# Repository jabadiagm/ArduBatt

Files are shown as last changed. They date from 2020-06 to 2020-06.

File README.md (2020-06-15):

# ArduBatt
Cargador de baterías con arduino y pantalla táctil

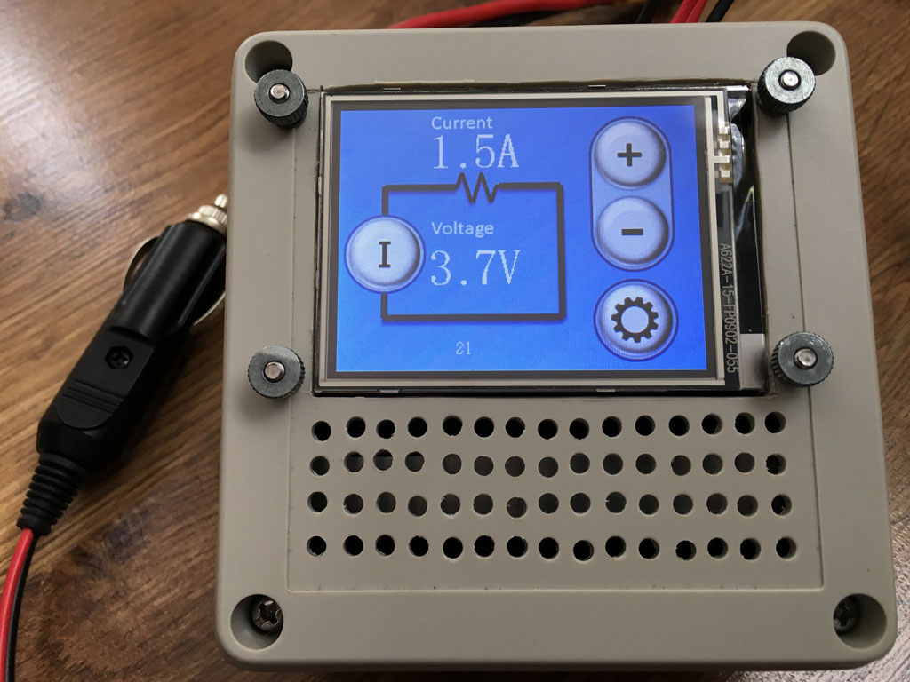
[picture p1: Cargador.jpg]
Cargador


Cargador de baterías basado en un convertidor push-pull de 30W, controlado por un atmega328p, el mismo que utiliza el arduino Uno. Esto permite usar las herramientas y librerías de arduino. El ajuste del cargador se hace desde una pantalla táctil Nextion, que se comunica con el atmega a través del puerto serie.

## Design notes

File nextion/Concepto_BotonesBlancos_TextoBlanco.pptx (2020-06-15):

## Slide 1

Current

0.2 A

+

+

+

V

Voltage

12.5 V

V

PAUSED

62% tamaño real

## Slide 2

Current

0.2 A

+

+

+

V

Voltage

12.5 V

V

PAUSED

62% tamaño real

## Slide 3

Current

0.2 A

+

+

+

V

Voltage

12.5 V

V

PAUSED

62% tamaño real

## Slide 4

Current

0.2 A

+

+

+

V

Voltage

12.5 V

PAUSED

V

62% tamaño real

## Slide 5

Settings

POWER MODE

Voltage
Current
Manual

<

a

V

a

I

a

M

62% tamaño real

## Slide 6

Sensors

<

Set=
PWM=

+

Vi=
Ii=
Vo=
Io=
T=

PAUSED

62% tamaño real

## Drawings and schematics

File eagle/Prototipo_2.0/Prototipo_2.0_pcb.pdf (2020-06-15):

1 2 3

TR1

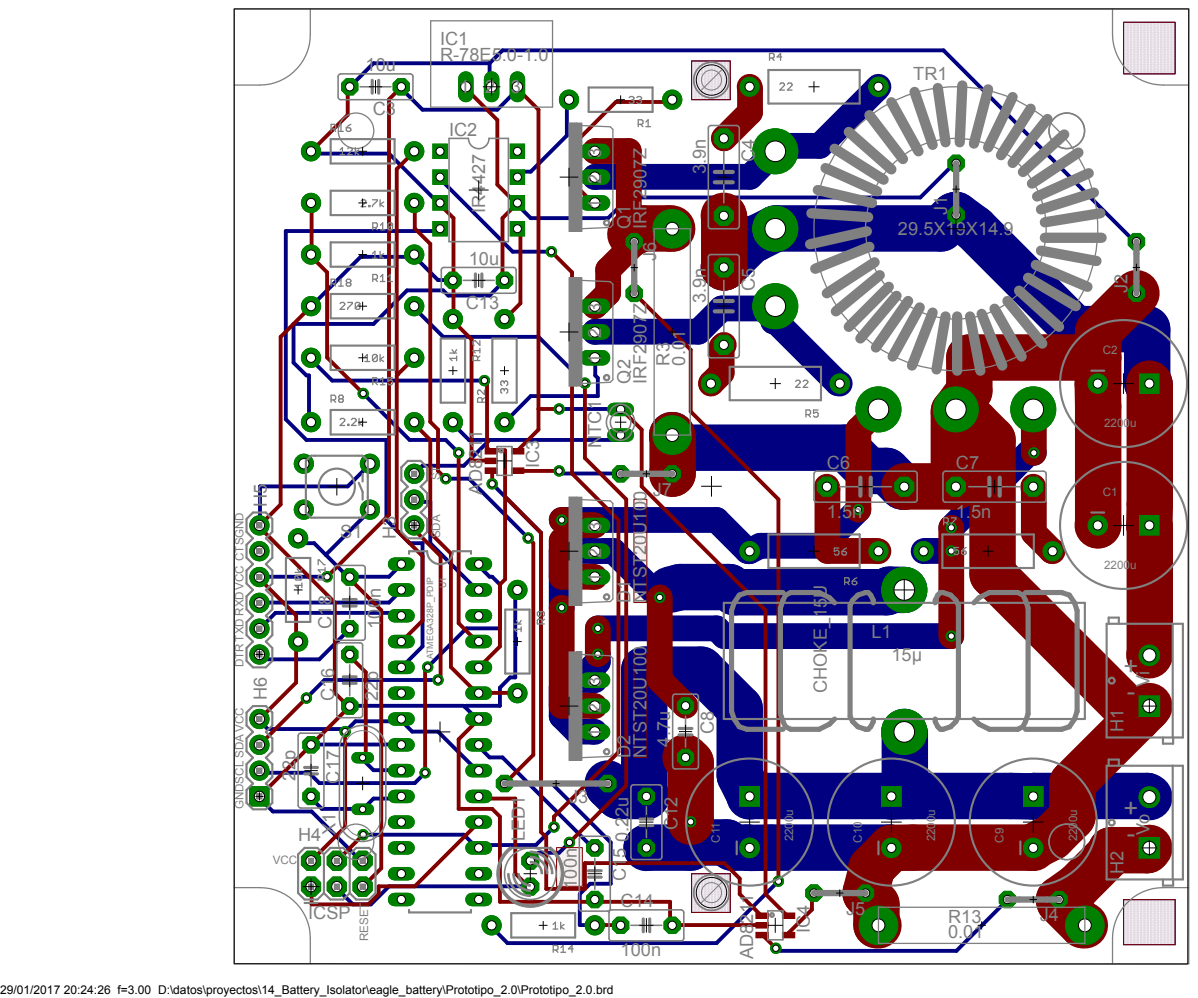
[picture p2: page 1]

DTR TXD RXDVCC CTSGND GNDSCL SDA VCC

L1
15µ

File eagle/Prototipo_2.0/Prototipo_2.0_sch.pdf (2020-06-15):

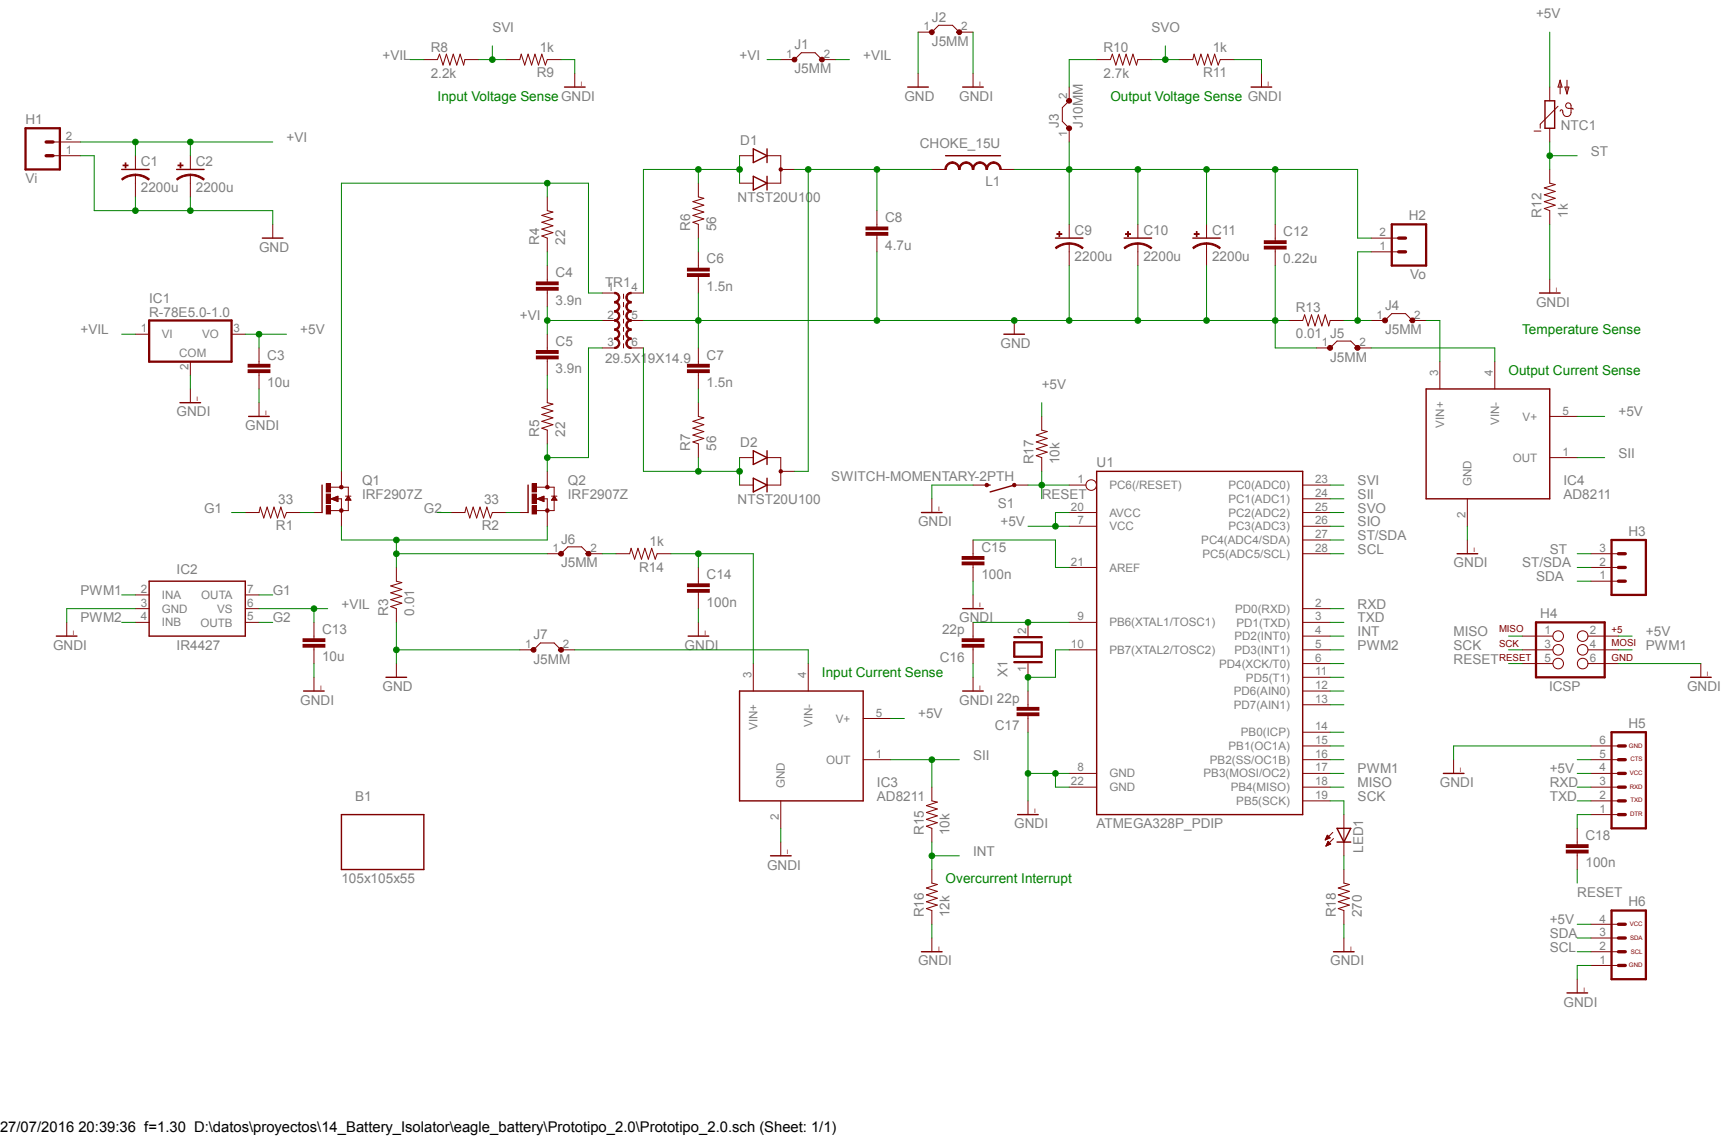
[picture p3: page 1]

27/07/2016 20:39:36 f=1.30 D:\datos\proyectos\14_Battery_Isolator\eagle_battery\Prototipo_2.0\Prototipo_2.0.sch (Sheet: 1/1) ⁵⁶

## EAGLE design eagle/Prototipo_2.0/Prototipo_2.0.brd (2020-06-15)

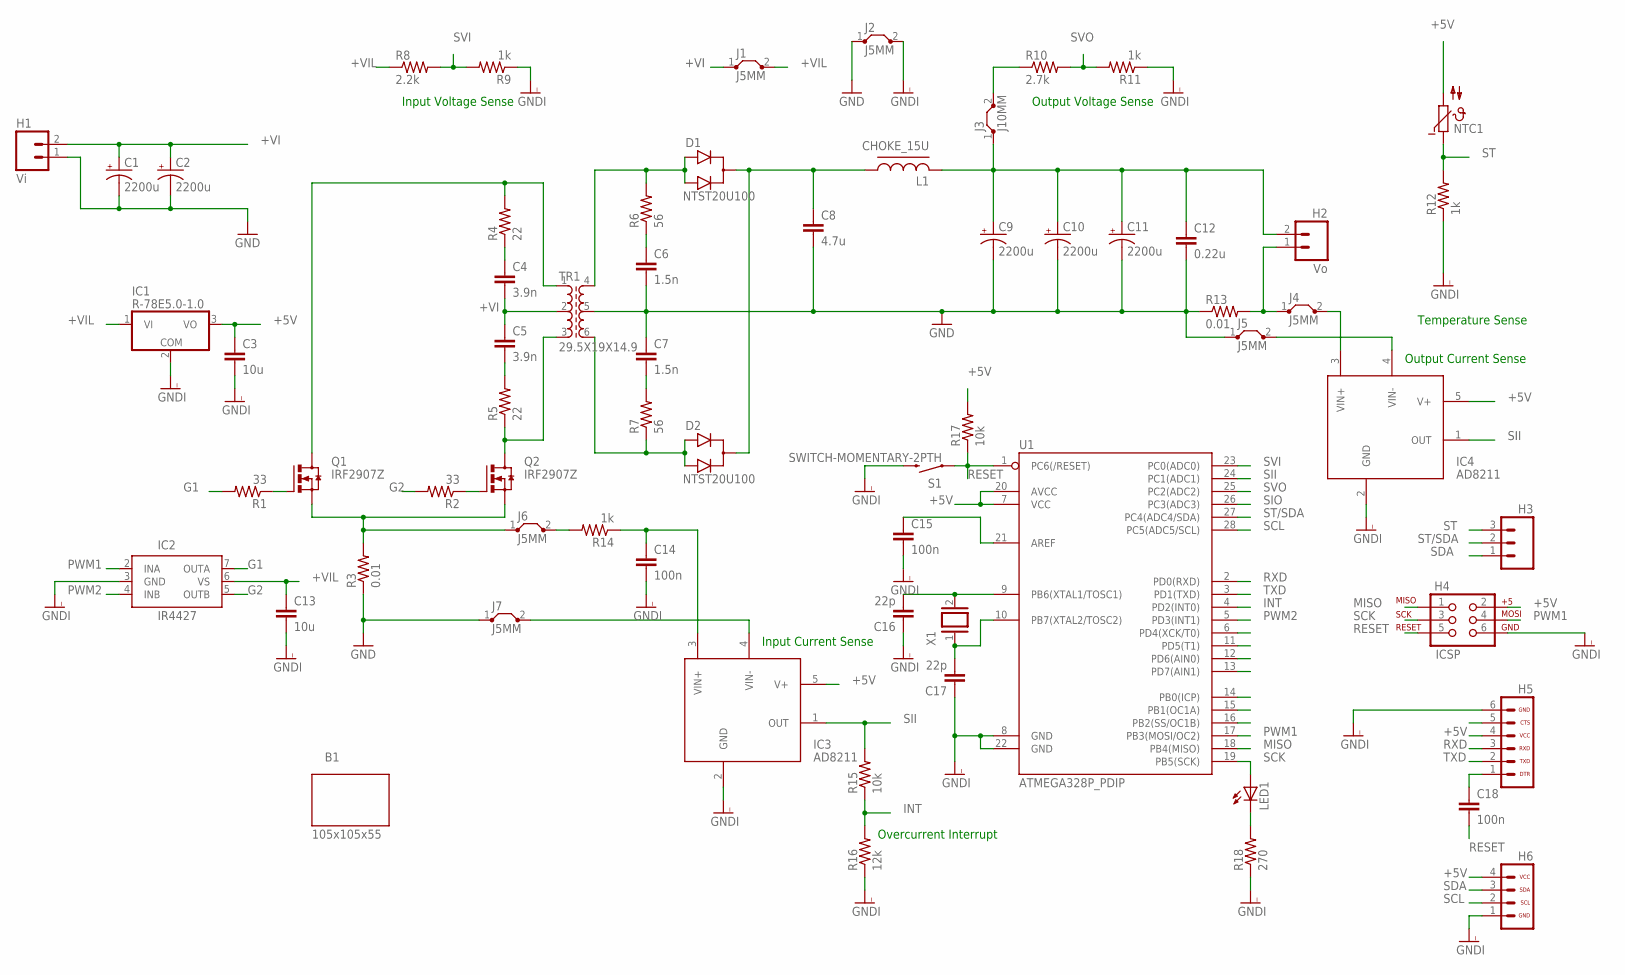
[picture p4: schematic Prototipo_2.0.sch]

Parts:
B1: 105x105x55; BOX_105X105X55
C1, C2, C9, C10, C11: 2200u; CPOL_RADIAL_12.5MM_5MM; MOUSER 667-EEU-FR1V222L
C3, C13: 10u; C5B2.5; MOUSER 810-FK26X7R1C106K
C4, C5: 3.9n; C7.5B3; MOUSER 594-K392K15X7RF53L2
C6, C7: 1.5n; C7.5B3; MOUSER 581-SR151C152KAR
C8: 4.7u; C5B2.5; MOUSER 81-RDEC71H475K2M1H3A
C12: 0.22u; C5B3; MOUSER 80-R82DC3220AA60K
C14, C15, C18: 100n; C5B3; MOUSER 80-R82DC3100AA50J
C16, C17: 22p; C5B2.5; MOUSER 140-50N5-220J-RC
D1, D2: NTST20U100; TO220V
H1: Vi; SCREWTERMINAL-5MM-2
H2: Vo; SCREWTERMINAL-5MM-2
H3: M03PTH; 1X03
H4: ICSP; 2X3
H5: HEADER_SERIAL
H6: HEADER_I2C
IC1: R-78E5.0-1.0
IC2: IR4427; DIL08
IC3, IC4: AD8211; RJ-5
J1, J2, J4, J5, J6, J7: J5MM; 05
J3: J10MM; 10
L1: CHOKE_15U; MOUSER 652-2200LL-150-H-RC
LED1: LED5MM
NTC1: NTC640; P640; MOUSER 594-NTCLE203E3502JB0
Q1, Q2: IRF2907Z; TO220V
R1, R2: 33; AXIAL-0.4; MOUSER 660-MF14DCT52R33R0F
R3, R13: 0.01; RSENSE; MOUSER 5W_66-OAR5R010JLF
R4, R5: 22; AXIAL-0.5; MOUSER 603-MFR50SFTE52-22R
R6, R7: 56; AXIAL-0.5; MOUSER 603-MFR50SFTE52-56R
R8: 2.2k; AXIAL-0.4; MOUSER 660-MF1/4DC1001F
R9, R11, R12, R14: 1k; AXIAL-0.4; MOUSER 660-MF1/4DC1001F
R10: 2.7k; AXIAL-0.4
R15, R17: 10k; AXIAL-0.4; MOUSER 660-MF1/4DC1002F
R16: 12k; AXIAL-0.4; MOUSER 660-MF1/4DCT52R1202F
R18: 270; AXIAL-0.4; MOUSER 660-MF1/4DC2700F
S1: SWITCH-MOMENTARY-2PTH; TACTILE-PTH
TR1: 29.5X19X14.9; CORE_29.5X19X14.9
U1: ATMEGA328P_PDIP; DIL28-3; MOUSER 556-ATMEGA328P-PU
X1: XTAL/S; QS

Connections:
$N1: C8.1, D1.2 (C), D2.2 (C), L1.1
+5V: C3.1, H4.2, H5.4 (4_VCC), H6.4 (4_VCC), IC1.3 (VO), IC3.5 (V+), IC4.5 (V+), NTC1.2, R17.P$2 (2), U1.7 (VCC), U1.20 (AVCC)
+VI: C1.+, C2.+, C4.2, C5.1, H1.2, J1.1, TR1.2
+VIL: C13.1, IC1.1 (VI), IC2.6 (VS), J1.2, R8.P$1 (1)
G1: IC2.7 (OUTA), R1.P$2 (2)
G2: IC2.5 (OUTB), R2.P$2 (2)
GND: C1.-, C2.-, C6.2, C7.1, C8.2, C9.-, C10.-, C11.-, C12.2, H1.1, J2.1, J5.1, J7.1, R3.P$1 (1), R13.P$1 (1), TR1.5
GNDI: C3.2, C13.2, C14.2, C15.2, C16.1, C17.1, H4.6, H5.6 (6_GND), H6.1 (1_GND), IC1.2 (COM), IC2.3 (GND), IC3.2 (GND), IC4.2 (GND), J2.2, R9.P$1 (1), R11.P$1 (1), R12.P$1 (1), R16.P$1 (1), R18.P$1 (1), S1.3 (2), U1.8 (GND), U1.22 (GND)
INT: R15.P$1 (1), R16.P$2 (2), U1.4 (PD2(INT0))
MISO: H4.1, U1.18 (PB4(MISO))
unnamed: Q1.1 (G), R1.P$1 (1)
unnamed: Q2.1 (G), R2.P$1 (1)
unnamed: C18.1, H5.1 (1_DTR)
unnamed: C7.2, R7.P$2 (2)
unnamed: C5.2, R5.P$2 (2)
unnamed: J3.2, R10.P$1 (1)
unnamed: C6.1, R6.P$1 (1)
unnamed: D1.1 (A1), D1.3 (A2), R6.P$2 (2), TR1.4
unnamed: D2.1 (A1), D2.3 (A2), R7.P$1 (1), TR1.6
unnamed: C9.+, C10.+, C11.+, C12.1, H2.2, J3.1, L1.2
unnamed: C4.1, R4.P$1 (1)
unnamed: Q1.2 (D), R4.P$2 (2), TR1.1
unnamed: Q2.2 (D), R5.P$1 (1), TR1.3
unnamed: J6.1, Q1.3 (S), Q2.3 (S), R3.P$2 (2)
unnamed: H2.1, J4.1, R13.P$2 (2)
unnamed: IC4.3 (VIN+), J4.2
unnamed: IC4.4 (VIN-), J5.2
unnamed: C14.1, IC3.3 (VIN+), R14.P$1 (1)
unnamed: IC3.4 (VIN-), J7.2
unnamed: J6.2, R14.P$2 (2)
unnamed: C16.2, U1.9 (PB6(XTAL1/TOSC1)), X1.2
unnamed: C17.2, U1.10 (PB7(XTAL2/TOSC2)), X1.1
unnamed: LED1.K (C), R18.P$2 (2)
unnamed: C15.1, U1.21 (AREF)
PWM1: H4.4, IC2.2 (INA), U1.17 (PB3(MOSI/OC2))
PWM2: IC2.4 (INB), U1.5 (PD3(INT1))
RESET: C18.2, H4.5, R17.P$1 (1), S1.1, U1.1 (PC6(/RESET))
RXD: H5.3 (3_RXD), U1.2 (PD0(RXD))
SCK: H4.3, LED1.A, U1.19 (PB5(SCK))
SCL: H6.2 (2_SCL), U1.28 (PC5(ADC5/SCL))
SDA: H3.1, H6.3 (3_SDA)
SII: IC3.1 (OUT), IC4.1 (OUT), R15.P$2 (2), U1.24 (PC1(ADC1))
SIO: U1.26 (PC3(ADC3))
ST: H3.3, NTC1.1, R12.P$2 (2)
ST/SDA: H3.2, U1.27 (PC4(ADC4/SDA))
SVI: R8.P$2 (2), R9.P$2 (2), U1.23 (PC0(ADC0))
SVO: R10.P$2 (2), R11.P$2 (2), U1.25 (PC2(ADC2))
TXD: H5.2 (2_TXD), U1.3 (PD1(TXD))

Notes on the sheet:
Temperature Sense
Input Voltage Sense
Output Voltage Sense
Output Current Sense
Input Current Sense
Overcurrent Interrupt

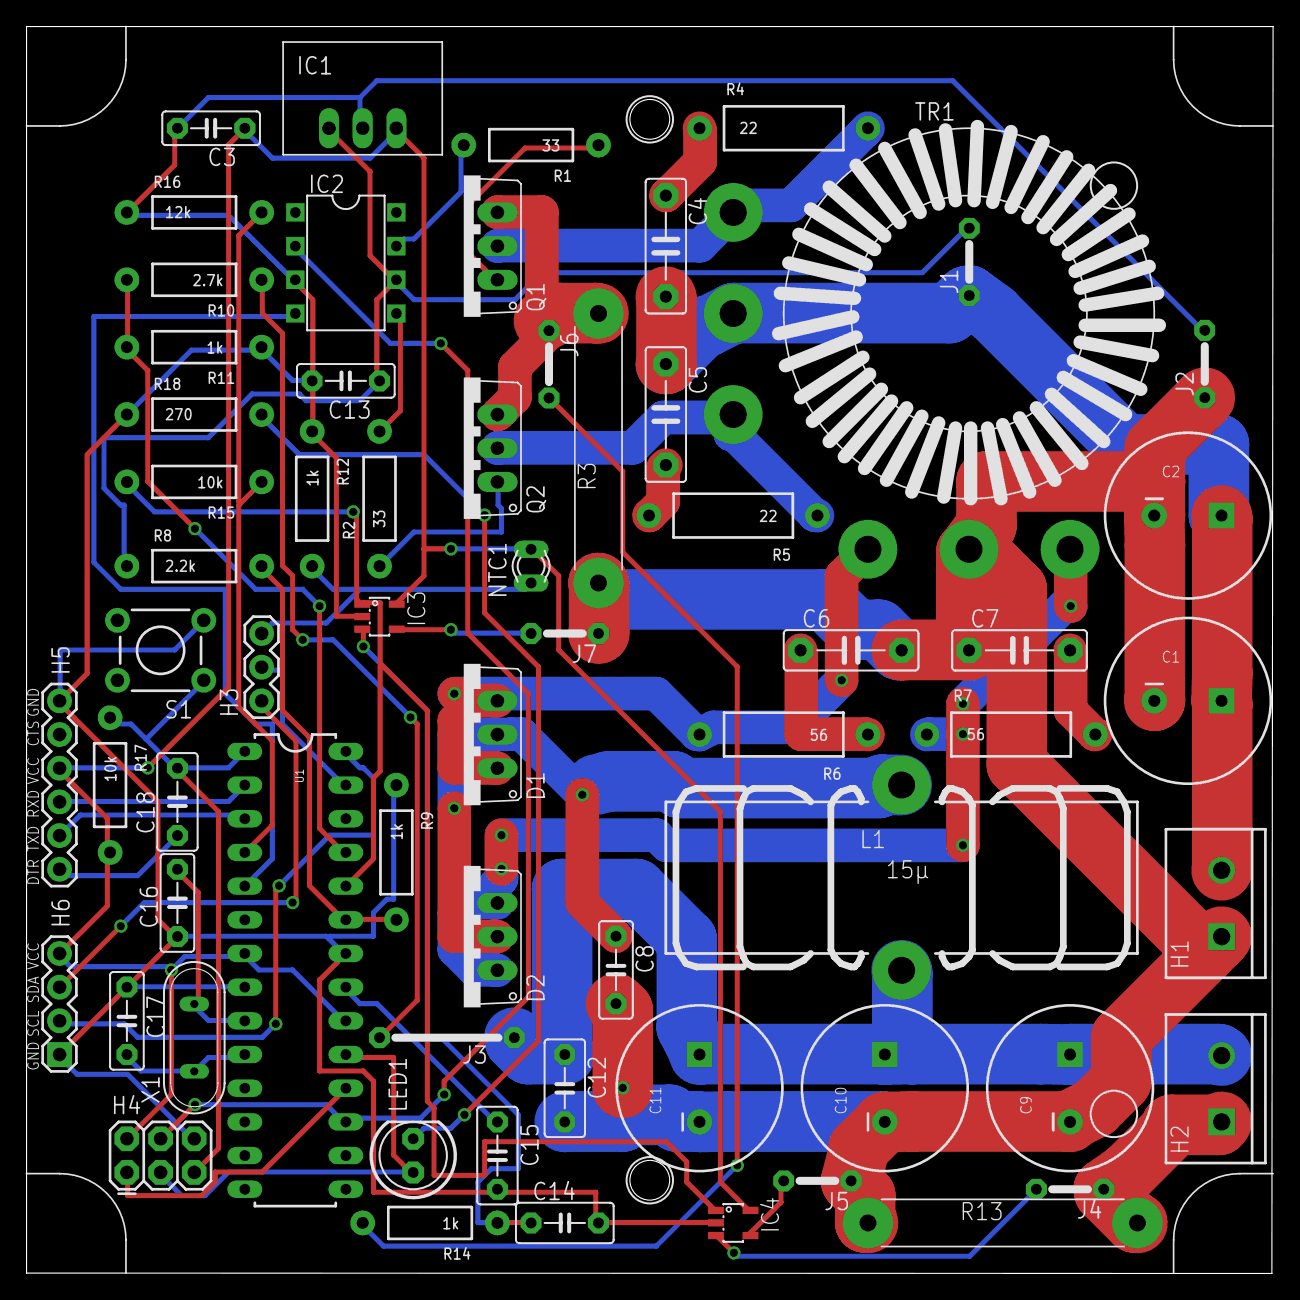
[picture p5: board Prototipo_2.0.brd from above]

Board: 2 copper layers, 94.0 x 94.0 mm, 65 parts (0 on the bottom side), 47 nets.

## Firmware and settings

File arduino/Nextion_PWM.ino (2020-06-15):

#include "D:\datos\Arduino\libraries\Timer2PWM\src\Timer2PWM.h"
#include "D:\datos\Arduino\libraries\Sensor\src\Sensor.h"
#include "D:\datos\Arduino\libraries\Nextion\src\Nextion.h"
#include "D:\datos\Arduino\libraries\Functions\src\Functions.h"
#include "D:\datos\Arduino\libraries\MemoryFree\MemoryFree.h"
#include "D:\datos\Arduino\libraries\PID\src\PID.h"

class Padre
{
public:
	Padre()
	{
		Serial.println("constructor Padre");
	}
	virtual void Comun()
	{
		Serial.println("Comun Padre");
	}
	virtual void Prueba()
	{
		Comun();
	}
};

class Hijo :public Padre
{
public:
	Hijo()
	{
		Serial.println(F("constructor Hijo"));
		//Padre();
	}
	void Comun()
	{
		Serial.println("Comun Hijo");
		Padre::Comun();
	}
};

class CtNextionPWM;


void blink() {
	pinMode(13, OUTPUT);
	long counter;
	for (counter = 0; counter < 3; counter++) {
		digitalWrite(13, HIGH);   // turn the LED on (HIGH is the voltage level)
		delay(1000);              // wait for a second
		digitalWrite(13, LOW);    // turn the LED off by making the voltage LOW
		delay(1000);              // wait for a second
	}

}


bool echo = false;
//float setpoint = 0; //voltage/current reference

void bip() { Serial.println("Bip"); }

// defines for setting and clearing register bits
#ifndef cbi
#define cbi(sfr, bit) (_SFR_BYTE(sfr) &= ~_BV(bit))
#endif
#ifndef sbi
#define sbi(sfr, bit) (_SFR_BYTE(sfr) |= _BV(bit))
#endif

void fastADC12_5()
//adjust prescaler to get faster conversion (12.5KHz)
{
	// set prescale to 64
	sbi(ADCSRA, ADPS2);
	sbi(ADCSRA, ADPS1);
	cbi(ADCSRA, ADPS0);
}

//page objects constants
//Events
const byte EV_POWERSHORTPRESS = 1;
const byte EV_POWERLONGPRESS = 2;
const byte EV_PLUSSHORTPRESS = 3;
const byte EV_PLUSLONGPRESS = 4;
const byte EV_MINUSSHORTPRESS = 5;
const byte EV_MINUSLONGPRESS = 6;
const byte EV_SETTINGSSHORTPRESS = 7;
const byte EV_SETTINGSLONGPRESS = 8;
const byte EV_BACKSHORTPRESS = 9;
const byte EV_BACKLONGPRESS = 10;
const byte EV_VOLTAGECHECKBOX = 11;
const byte EV_CURRENTCHECKBOX = 12;
const byte EV_MANUALCHECKBOX = 13;
//Variables
const byte VAR_SENSORVI = 128;
const byte VAR_SENSORII = 129;
const byte VAR_SENSORVO = 130;
const byte VAR_SENSORIO = 131;
const byte VAR_SENSORT = 132;
const byte VAR_FSETPOINT = 133;
const byte VAR_ISETPOINT = 134;
const byte VAR_POWERMODE = 135;
const byte VAR_LOOPSTATUS = 136;



typedef enum enumLoopStatus {
	lsStop = 0,
	lsPause = 1,
	lsRun = 2,
	lsMalfunction = 3,
	lsNoState=99
} ;

typedef enum powerMode {
	pmVoltage=0,
	pmCurrent=1,
	pmManual=2
};


class iCtNextionPWM {
public:
	virtual void Init() {}
	virtual void ShowMain() {}
	virtual void ShowMainVoltage() {}
	virtual void ShowMainCurrent() {}
	virtual void ShowMainManual() {}
	virtual void ShowSettings() {}
	virtual void ShowSensors() {}
	virtual void ShowSensorsVoltage() {}
	virtual void ShowSensorsCurrent() {}
	virtual void ShowSensorsManual() {}
	virtual void ShowAlarm(char *alarmText) {}
	virtual void ProcessEvent(byte eventId) {} //button click
	virtual void DisplayVariables() {} //show variables during loop
	virtual void DisplayVariable(byte variableId) {} //show single variable
};

class config {
public:
	config();
	powerMode pwMode;
	float fSetpoint; //voltage/current reference
	int iSetpoint; //manual mode reference
	bool nextionOK; //true when screen is ready
	const float INCREMENTVOLTAGE=0.5; // +/- 0.5V
	const float INCREMENTCURRENT = 0.1; // +/- 0.1A
	const int INCREMENTMANUAL = 1; // +/-1 in pwm
	const float MAXVOLTAGE = 20; //maximum output voltage
	const float MAXCURRENT = 4; //maximum current
	const int MAXMANUAL = 127; //maximum pwm value
	const int MINMANUAL = 0; //minimum pwm value due to switching dead times
	const unsigned long TIMEADQUIREDATA = 500; //time (us) to read analog sensors
	const unsigned long TIMECONTROL = 5000; // 5000; //time (us) to control
	const unsigned long TIMEREFRESHDATA = 1000; //time (ms) to update screen data
	const int TIMESHORTPRESS = 450; //max time to keep pressing a button to take as short press
private:
}config;

config::config(){
	pwMode = pmVoltage;
	nextionOK = false;
	iSetpoint = MINMANUAL;
	fSetpoint = 0;
}


struct NextionListener : public NextionEvent
{
	using NextionEvent::Event;

	void Event(char *eventText)
	{
		static unsigned long timeButtonPress; //when a button was last pressed
#if defined(__AVR_ATmega1280__) || defined(__AVR_ATmega2560__)
		Serial.print("Event:");
		Serial.println(eventText);
#endif
		//main screen
		//+ button
		if (strcmp_P(eventText, PSTR("65000201")) == 0) { //+ button pressed
			timeButtonPress = millis();
		}
		if (strcmp_P(eventText,PSTR( "65000200")) == 0) { //+ button released
			if ((millis() - timeButtonPress) < config.TIMESHORTPRESS) {
				//buttonPlusShortPress();
				Controller->ProcessEvent(EV_PLUSSHORTPRESS);
			}
			else {
				//buttonPlusLongPress();
				Controller->ProcessEvent(EV_PLUSLONGPRESS);
			}
		}
		//- button
		if (strcmp_P(eventText, PSTR("65000301")) == 0) { //- button pressed
			timeButtonPress = millis();
		}
		if (strcmp_P(eventText, PSTR("65000300")) == 0) { //- button released
			if ((millis() - timeButtonPress) < config.TIMESHORTPRESS) {
				//buttonMinusShortPress();
				Controller->ProcessEvent(EV_MINUSSHORTPRESS);
			}
			else {
				//buttonMinusLongPress();
				Controller->ProcessEvent(EV_MINUSLONGPRESS);
			}
		}
		//power button
		if (strcmp_P(eventText, PSTR("65000501")) == 0) { //power button pressed
			timeButtonPress = millis();
		}
		if (strcmp_P(eventText, PSTR("65000500")) == 0) { //power button released
			if ((millis() - timeButtonPress) < config.TIMESHORTPRESS) {
				//buttonPowerShortPress();
				Controller->ProcessEvent(EV_POWERSHORTPRESS);
			}
			else {
				//buttonPowerLongPress();
				Controller->ProcessEvent(EV_POWERLONGPRESS);
			}
		}
		//settings button
		if (strcmp_P(eventText, PSTR("65000401")) == 0) { //settings button pressed
			timeButtonPress = millis();
		}
		if (strcmp_P(eventText, PSTR("65000400")) == 0) { //settings button released
			if ((millis() - timeButtonPress) < config.TIMESHORTPRESS) {
				//buttonSettingsShortPress();
				Controller->ProcessEvent(EV_SETTINGSSHORTPRESS);
			}
			else {
				//buttonSettingsLongPress();
				Controller->ProcessEvent(EV_SETTINGSLONGPRESS);
			}
		}
		//settings screen
		//back button
		if (strcmp_P(eventText, PSTR("65010101")) == 0) { //back button pressed
			timeButtonPress = millis();
		}
		if (strcmp_P(eventText, PSTR("65010100")) == 0) { //back button released
			if ((millis() - timeButtonPress) < config.TIMESHORTPRESS) {
				//buttonBackShortPress();
				Controller->ProcessEvent(EV_BACKSHORTPRESS);
			}
			else {
				//buttonBackLongPress();
				Controller->ProcessEvent(EV_BACKLONGPRESS);
			}
		}
		//voltage checkbox
		if (strcmp_P(eventText, PSTR("65010201")) == 0) { 
			//checkVoltagePress();
			Controller->ProcessEvent(EV_VOLTAGECHECKBOX);
		}

		//current checkbox
		if (strcmp_P(eventText,PSTR("65010301")) == 0) {
			//checkCurrentPress();
			Controller->ProcessEvent(EV_CURRENTCHECKBOX);
		}

		//manual checkbox
		if (strcmp_P(eventText, PSTR("65010401")) == 0) {
			//checkManualPress();
			Controller->ProcessEvent(EV_MANUALCHECKBOX);
		}
		//sensors screen
		//back button
		if (strcmp_P(eventText, PSTR("65020D01")) == 0) { //back button pressed
			timeButtonPress = millis();
		}
		if (strcmp_P(eventText, PSTR("65020D00")) == 0) { //back button released
			if ((millis() - timeButtonPress) < config.TIMESHORTPRESS) {
				//buttonBackShortPress();
				Controller->ProcessEvent(EV_BACKSHORTPRESS);
			}
			else {
				//buttonBackLongPress();
				Controller->ProcessEvent(EV_BACKLONGPRESS);
			}
		}
		//power button
		if (strcmp_P(eventText, PSTR("65020301")) == 0) { //power button pressed
			timeButtonPress = millis();
		}
		if (strcmp_P(eventText, PSTR("65020300")) == 0) { //power button released
			if ((millis() - timeButtonPress) < config.TIMESHORTPRESS) {
				//buttonPowerShortPress();
				Controller->ProcessEvent(EV_POWERSHORTPRESS);
			}
		}
		//+ button
		if (strcmp_P(eventText, PSTR("65020401")) == 0) { //+ button pressed
			timeButtonPress = millis();
		}
		if (strcmp_P(eventText, PSTR("65020400")) == 0) { //+ button released
			if ((millis() - timeButtonPress) < config.TIMESHORTPRESS) {
				//buttonPlusShortPress();
				Controller->ProcessEvent(EV_PLUSSHORTPRESS);
			}
			else {
				//buttonPlusLongPress();
				Controller->ProcessEvent(EV_PLUSLONGPRESS);
			}
		}
		//- button
		if (strcmp_P(eventText, PSTR("65020501")) == 0) { //- button pressed
			timeButtonPress = millis();
		}
		if (strcmp_P(eventText, PSTR("65020500")) == 0) { //- button released
			if ((millis() - timeButtonPress) < config.TIMESHORTPRESS) {
				//buttonMinusShortPress();
				Controller->ProcessEvent(EV_MINUSSHORTPRESS);
			}
			else {
				//buttonMinusLongPress();
				Controller->ProcessEvent(EV_MINUSLONGPRESS);
			}
		}
	}
	iCtNextionPWM *Controller;
} NextionListener;



/*void echo_string_serial(char *line, int n_bytes) {
	int counter;
	char output[200];
	hex_string2string(line, n_bytes, output);
	output[2 * n_bytes] = 0;
	echo_println(output);
} */
void echo_print(String line) {
	if (echo) Serial.print(line);
}
void echo_println(String line) {
	if (echo) Serial.println(line);
}

#if defined(__AVR_ATmega1280__) || defined(__AVR_ATmega2560__)
	Nextion screen(&Serial3, &NextionListener);
#else
	Nextion screen(&Serial, &NextionListener);
#endif
enumLoopStatus loopStatus = lsStop;


struct AlarmListener : public AlarmEvent
{
	using AlarmEvent::Alarm;

	void Alarm(String AlarmText)
	{
		//if the screen is working, show error in status line. if not, send by serial
		byte ret;
		char command[30]="";
		//String command;
		loopStatus = lsMalfunction; 
		Timer2PWM.end(); //stop power
		if (config.nextionOK == true) {
			AlarmText.toCharArray(command, AlarmText.length()+1,0);
			Controller->ShowAlarm(command);
			/*
			//if (config.pageNumber != 0) buttonBackShortPress(); //alarms are shown in main screen
			ret = screen.sendCommand("t2.pco=63488"); //status line to red
			if (!ret) {
				command = "t2.txt=\"" + AlarmText + "\"";
			}
			if (!ret) ret = screen.sendCommand(command);
			if (!ret) ret = screen.sendCommand("ref t2");
			
			//change power icon to red
			switch (config.pwMode) {
			case pmVoltage:
				if (!ret) ret = screen.sendCommand("b3.picc=3");
				break;
			case pmCurrent:
				if (!ret) ret = screen.sendCommand("b3.picc=7");
				break;
			case pmManual:
				if (!ret) ret = screen.sendCommand("b3.picc=11");
				break;
			}
			if (!ret) ret = screen.sendCommand("t0.txt=\"0A\""); //current to 0
			if (!ret) ret = screen.sendCommand("t1.txt=\"0V\""); //voltage to 0
			if (!ret) ret = screen.sendCommand("ref b3"); */
		}
		if (config.nextionOK == false || ret!=0) {
			byte counter;
			while (1) {
				Serial.println(AlarmText);
				for (counter = 0; counter < 50; counter++) {
					digitalWrite(13, HIGH);
					delay(25);
					digitalWrite(13, LOW);
					delay(25);
				}
			}
		}
	}
	iCtNextionPWM *Controller;
} AlarmListener;

SENSOR SensorVi(0, 0.0156, "Vi", 22, &AlarmListener,40, (float)config.TIMEADQUIREDATA / 1000000); //input voltage
SENSOR SensorIi(1, 0.0244, "Ii", 200, &AlarmListener,1, (float)config.TIMEADQUIREDATA / 1000000); //input current
SENSOR SensorVo(2, 0.018, "Vo", 20, &AlarmListener,50, (float)config.TIMEADQUIREDATA / 1000000); //output voltage
SENSOR SensorIo(3, 0.0244, "Io", 15, &AlarmListener,200,(float)config.TIMEADQUIREDATA/1000000); //output current
NTC5K25 SensorT(4, "T", 70, &AlarmListener); //Temperature
fPID ControllerI(2, 10, 0, (float)config.TIMECONTROL/1000000);
fPID ControllerV(0.01, 0.2, 0, (float)config.TIMECONTROL/1000000);

unsigned long counterAdquire=0; //number of times adquire() is called
unsigned long counterControl = 0; //number of times control() is called
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
void loop()
{
	String command;
	String response;
	

	/*long counter;
	Serial.begin(38400);
	config.pwMode = pmVoltage;
	config.fSetpoint = 5;
	run();
	for (counter = 0; counter < 500000; counter++) {

		adquire();
		control();
		showSerialData();
		stats();
		//Serial.println(SensorIo.getLast());
		//delay(50);
	}
	pause();
	while (1); */
	
	unsigned long timeLastSet = 0;
	while (true) {
		switch (loopStatus) {
			case lsStop :
				//initialization
#if defined(__AVR_ATmega1280__) || defined(__AVR_ATmega2560__)
				Serial.begin(38400); //init serial
#endif
				nextionInit(); //init screen
				if (config.nextionOK) loopStatus = lsPause;
				CtNextionPWM.ShowMainCurrent();
				break;
			case lsPause:
				//waiting to start. sensors running
				adquire();
				showData(false);
#if defined(__AVR_ATmega1280__) || defined(__AVR_ATmega2560__)
				//stats();
				//showSerialData();
#endif
				break;
			case lsRun:
				//PWM+sensors running
				adquire();
				control();
				showData(false);
				//stats();
#if defined(__AVR_ATmega1280__) || defined(__AVR_ATmega2560__)
				
				//showSerialData();
#endif
				break;
			case lsMalfunction:

				break;
		}

#if defined(__AVR_ATmega1280__) || defined(__AVR_ATmega2560__)
		while (Serial.available()) {
			int inByte = Serial.read();
			//Serial.print(inByte, HEX);
			if (inByte == 0xd) { //carriage return
				screen.sendCommand(command, response);
				Serial.print("Command:");
				Serial.println(command);
				Serial.print("Response:");
				Serial.println(response);
				command = "";
				response = "";
			} else command.concat(char(inByte));
		}
#endif
		
		//while ((millis() - timeLastSet) < 1 && millis() >= timeLastSet);
		//timeLastSet = millis();
		screen.checkEvent();
		//delay(500);
	}

  /* add main program code here */

}

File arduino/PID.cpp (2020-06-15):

/*
PID.h - Library for PID control.
J. Castillejo, May 16th, 2017.
Released into the public domain.
*/

#include "Arduino.h"
#include "PID.h"

//float PID
fPID::fPID(float gainProportional, float gainIntegral, float gainDerivative, float sampleTime)
{
	//basic PID, extra items disabled
	T = sampleTime;
	kp = gainProportional;
	ki = gainIntegral;
	kd = gainDerivative/T; //T included in kp to save one floating point operation in calculations
	if (kp != 0) activeP = true;
	else activeP = false;
	if (ki != 0) activeI = true;
	else activeI = false;
	if (kd != 0) activeD = true;
	else activeD = false;
	kick = false;
	dFilter = false; //filters disabled by default
	oFilter = false; //filters disabled by default
	oLimits = false; //saturation disabled by default
	windUp = false; //anti windup protection disabled by default
	reset();

}

void fPID::reset()
//restart previous variables
{
	IPrev = 0;
	errorPrev = 0;
	errorDPrev = 0;
	DPrev = 0;
	errorIPrev = 0;
	outputSatPrev = 0;
	outputPrev = 0;
	firstStep = true;
}

void fPID::setDerivative(bool kickProtection, float freqFilterDerivative)
//kickProtection=true -> discard reference in derivative term to prevent spikes. 
//                       use if reference is constant
//freqFilterDerivative=frequency (Hz) of low-pass filter in derivative term
//                     to avoid stability problems
{
	kick = kickProtection; //if true, discard reference to avoid spikes
	fd = freqFilterDerivative;
	if (fd != 0) {
		dFilter = true;
		alphaD = 2*PI*T*fd / (2*PI*T*fd + 1); //freq->alpha
	}
}

void fPID::setOutputLimits(float outputMax, float outputMin)
//define saturation values
{
	oMax = outputMax; //output can't be over oMax
	oMin = outputMin; //output can't be under oMin
	oLimits = true;
}

void fPID::setAntiWindUp(float outputMax, float outputMin, float windUpGain)
//define saturation values and antiwindup feedback constant
//windUpGain : feedback constantto avoid windup issues
{
	setOutputLimits(outputMax, outputMin);
	kt = windUpGain;
	windUp = true;
}

void fPID::setOutputFilter(float freqOutputFilter)
//freqOutputFilter = frequency (Hz) of low-pass filter in output to limit slew rate
{
	fo = freqOutputFilter;
	alphaO = 2 * PI*T*fo / (2 * PI*T*fo + 1); //freq->alpha
	oFilter = true;
}


/*
 error      ---
-----------| P |---------------
      |     ---                |
      |                        |
      |     ---    ---   --    |
      |----| D |--| s |-|fd|--(+)
      |     ---    ---   --    |
      |                        |             -----
      |     ---         ---    |     --     |   _ |         control
       ----| I |--(+)--|1/s|--(+)---|fo|----| _/  |---------
            ---    |    ---       |  --     |     |   |
                   |              |          -----    |
                   |    ---       |                   |
                    ---| kt|-----(-)------------------
                        ---
*/

float fPID::calculate(float setPoint, float measurement)
{
	float P=0; //proportional term
	float I=0; //integral term
	float D=0; //derivative term
	float outputFilter; //output before filter
	float outputSat; //output before saturation
	float output; //output after saturation
	error = setPoint - measurement;
	if (activeP) {
		P = kp*error;
		//Serial.print("P=");
		//Serial.println(P, 10);
	}
	if (activeD) {
		if (kick) errorD = -measurement*kd;
		else errorD = error*kd;
		if (firstStep) {
			errorDPrev = errorD; //avoid spikes at startup
			firstStep = false;
		}
		DFilt = errorD - errorDPrev; //derivative calculation (T included in kd)
		if (dFilter) D = alphaD*DFilt + (1 - alphaD)*DPrev;
		else D = DFilt;
	}
	if (activeI) {	
		if (windUp) errorI = ki*error + kt*(outputPrev - outputSatPrev);
		else errorI = ki*error;
		I = IPrev + 0.5*T*(errorI + errorIPrev); //euler integration
		//Serial.print("I=");
		//Serial.println(I, 10);
	}
	outputFilter = P + I + D; //combine terms
	if (oFilter) outputSat = alphaO*outputFilter + (1 - alphaO)*outputSatPrev;
	else outputSat = outputFilter;
	if (oLimits) {
		if (outputSat > oMax) output = oMax;
		else if (outputSat < oMin) output = oMin;
		else output = outputSat;
	} else {
		output = outputSat;
	}
	//Serial.print("output=");
	//Serial.println(output, 10);
	//save values for next interval
	IPrev = I;
	errorPrev = error;
	errorDPrev = errorD;
	DPrev = D;
	errorIPrev = errorI;
	outputSatPrev = outputSat;
	outputPrev = output;
	return output;
}

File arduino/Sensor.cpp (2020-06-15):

/*
  Morse.cpp - Library for flashing Morse code.
  Created by David A. Mellis, November 2, 2007.
  Released into the public domain.
*/

#include "Arduino.h"
#include "Sensor.h"

SENSOR::SENSOR(int pin, float scaleFactor, String name, float maximum,AlarmEvent *alarm, float freqFilter, float sampleTime)
{
	inputPin = pin;
	factor = scaleFactor;
	sensorName = name;
	maxValue = maximum;
	_alarm = alarm;
	Ts = sampleTime;
	output = 0;
	if (freqFilter == 0) {
		filter = false;
		//alphaFilter = 1;
	} else { //second order butterworth filter
		filter = true;
		//alphaFilter = 2 * PI*sampleTime*freqFilter / (2 * PI*sampleTime*freqFilter + 1); //
		ff = sampleTime * freqFilter;
		const double ita = 1.0 / tan(M_PI*ff);
		const double q = sqrt(2.0);
		b0 = 1.0 / (1.0 + q*ita + ita*ita);
		b1 = 2 * b0;
		b2 = b0;
		a1 = 2.0 * (ita*ita - 1.0) * b0;
		a2 = -(1.0 - q*ita + ita*ita) * b0;
		

	}
}

float SENSOR::getNew()
{
	/*const float A = 10; //sin test function
	const float f = 100;
	static float t;
	static long N = 0;
	N++;
	t = N*Ts;
	value = 10 * sin(2 * PI*f*t); */
	value = factor*analogRead(inputPin);
	//if (filter) output = alphaFilter*value + (1 - alphaFilter)*output;
	if (filter) {
		output = b0*value + b1*value_1 + b2*value_2 + a1*output_1 + a2*output_2;
		value_2 = value_1;
		value_1 = value;
		output_2 = output_1;
		output_1 = output;
	}
	else output = value;
	if (value>maxValue)
	{
		String errorMsg;
		char buffer1[10];
		char buffer2[10];
		dtostrf(value, 4, 2, buffer1);
		dtostrf(maxValue, 4, 2, buffer2);
		errorMsg = sensorName + "=" + String(buffer1) +">" + String(buffer2);
		_alarm->Alarm(errorMsg);
	}
	return output;
}
float SENSOR::getLast()
{
	return output;
}

SENSORRAW::SENSORRAW(int pin, String name, int maximum, AlarmEvent *alarm)
{
	inputPin = pin;
	sensorName = name;
	maxValue = maximum;
}

int SENSORRAW::getNew()
{
	value = analogRead(inputPin); //+0.01*value;
	if (value>maxValue)
	{
		String errorMsg;
		errorMsg = sensorName + "=" + String(value) + ">" + String(maxValue);
		_alarm->Alarm(errorMsg);
	}
	return value;
}

int SENSORRAW::getLast()
{
	return value;
}

NTC5K25::NTC5K25(int inputPin, String name, int maximum, AlarmEvent *alarm)
{
	ntcPin = inputPin; //arduino input attached to sensor
					   //analog values table
	ntc5k25AN[0] = 75;
	ntc5k25AN[1] = 171;
	ntc5k25AN[2] = 321;
	ntc5k25AN[3] = 501;
	ntc5k25AN[4] = 667;
	ntc5k25AN[5] = 792;
	ntc5k25AN[6] = 876;
	ntc5k25AN[7] = 928;
	//factors table: 20/(ntc5k25AN[k+1]-ntc5k25AN[k])
	ntc5k25Factor[0] = 0.20887;
	ntc5k25Factor[1] = 0.13268;
	ntc5k25Factor[2] = 0.11107;
	ntc5k25Factor[3] = 0.12075;
	ntc5k25Factor[4] = 0.16018;
	ntc5k25Factor[5] = 0.23808;
	ntc5k25Factor[6] = 0.38157;
	sensorName = name;
	maxValue = maximum;
	_alarm = alarm;
}

int NTC5K25::getNew()
//access sensor
//  +5V------|NTC|---|1K|-----
//                 |         _|_
//            arduino pin
//
//sensor and resistor form a voltage divider. temperature is obtained
//by interpolating in lookup table
{
	int analog; //analogRead from the input pin
	register byte counter;
	analog = analogRead(ntcPin);
	//Serial.print ("analog=");
	//Serial.println (analog);
	for (counter = 0; counter<7; counter++)
	{
		if (analog >= ntc5k25AN[counter] && analog <= ntc5k25AN[counter + 1]) //interpolation
		{
			value = (analog - ntc5k25AN[counter])*ntc5k25Factor[counter] + 20 * counter + 5;
			break;
		}
	}
	if (counter>7)
	{
		//value out of table
		if (analog<ntc5k25AN[0]) //lower than 5ºC 
		{
			value = -200;
		}
		else
		{
			value = 666; //hotter than 145 ºC 
		}
	}
	if (value>maxValue)
	{
		String errorMsg;
		errorMsg = sensorName + "=" + String(value) + ">" + String(maxValue);
		_alarm->Alarm(errorMsg);
	}
	return value;
}

int NTC5K25::getLast()
{
	return value;
}

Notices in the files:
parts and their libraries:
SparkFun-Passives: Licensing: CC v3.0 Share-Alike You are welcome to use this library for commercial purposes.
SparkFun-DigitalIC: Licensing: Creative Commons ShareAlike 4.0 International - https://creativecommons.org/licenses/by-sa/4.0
